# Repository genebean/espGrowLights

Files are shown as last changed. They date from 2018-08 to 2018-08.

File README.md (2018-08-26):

# espGrowLights

espGrowLights is an Arduino sketch for setting up a NodeMCU 1.0 (ESP-12E) to
control the grow lights for our house plants.

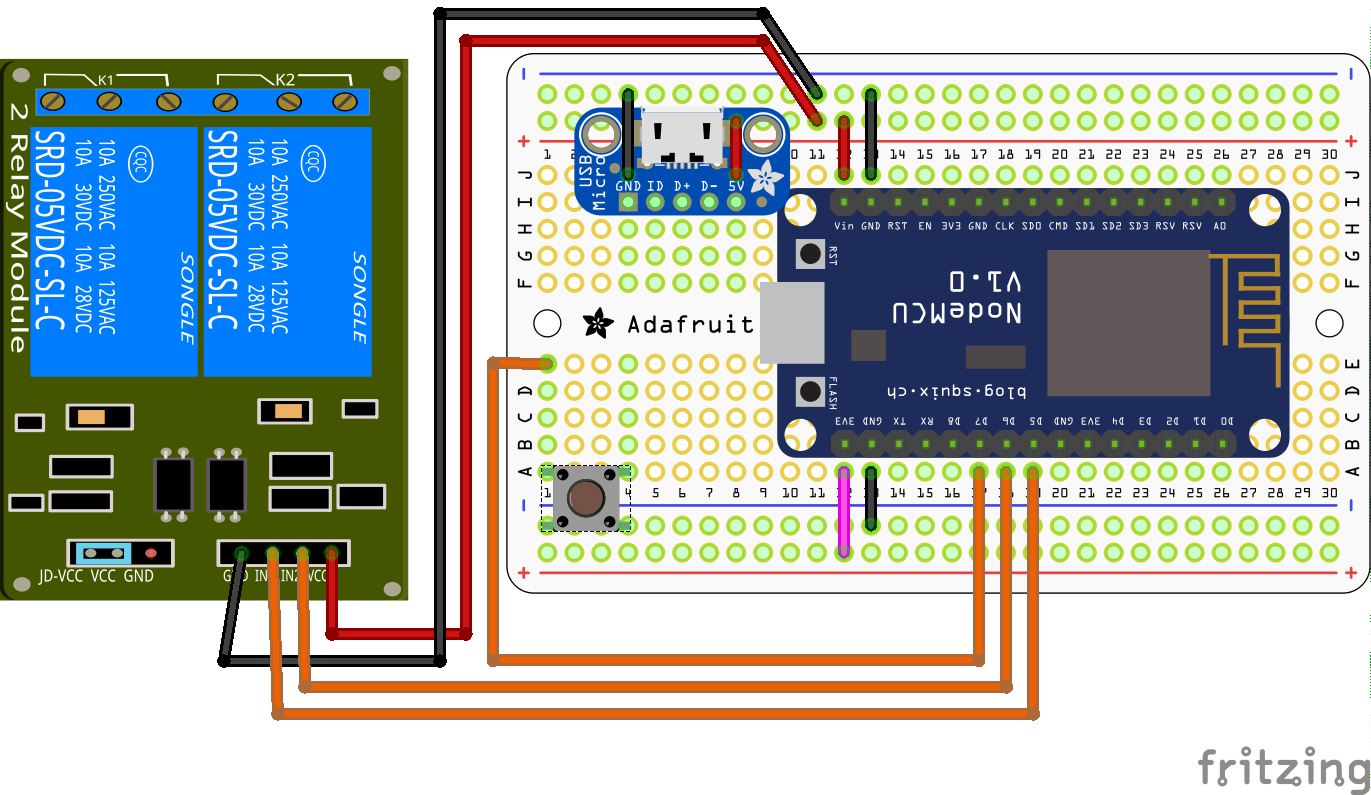
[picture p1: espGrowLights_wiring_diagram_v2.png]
Fritzing wiring diagram v1


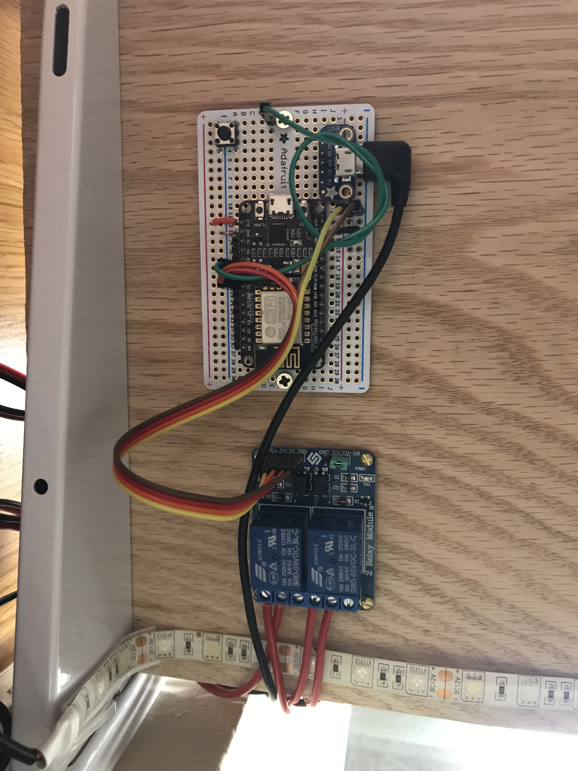
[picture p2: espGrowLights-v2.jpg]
Photo of espGrowLight-v2


To use this sketch you will need to copy `config.sample.h` to
`config.h` and edit it for your wifi (these modules only support 2.4GHz).
You may also want to change the device names in `config.sample.h`.

## Usage

espGrowLights emulates two Belkin Wemo smart plugs that can be
discovered by an Echo so long as they are on the same network. The first device
is the builtin LED. The second controls both relays.

### Alexa

To turn on the grow lights simply say "Alexa, turn on the disco lights."
To trun on the on board led you can say "Alexa, turn on the esp led."

_You may have noticed that I call the grow lights disco lights... thats because
Alexa kept thinking I was saying "garage lights" when I actually said
"grow lights." The lights have a bit of a disco feel and that is not similar to
other words so it should keep her from getting cofused._

### Button

There is also a momentary push button on the edge of the board that can be used
to toggle the grow lights on or off. The code for this button includes logic to
make it only respond about every 3 seconds after its first pressed. This is so
that you don't end up rappidly turning the lights on and off multiple times. If
you want to toggle the lights more than once you can either wait a moment or
just hold the button down.

### Auto on/off schedule

A schedule has also been incorporated into this so that our lights turn
themselves on every morning and off every evening. The on and off hours are also
in `config.sample.h`. Note that the off hour uses the 24-hour format. Lastly,
note also that there are also settings for your timezone. I have included sample
entries for UTC and US Eastern (with and without daylight savings).

## Updates and troubleshooting

I've added mDNS so that you can verify the device is up by browsing to
http://espGrowLights.local or pinging `espGrowLights.local`. That name
corresponds to the `HOST_NAME` entry in `config.sample.h`. This page also acts
as a sudo console that displays log messages. This allows for basic debugging
withoug connecting to the serial port.

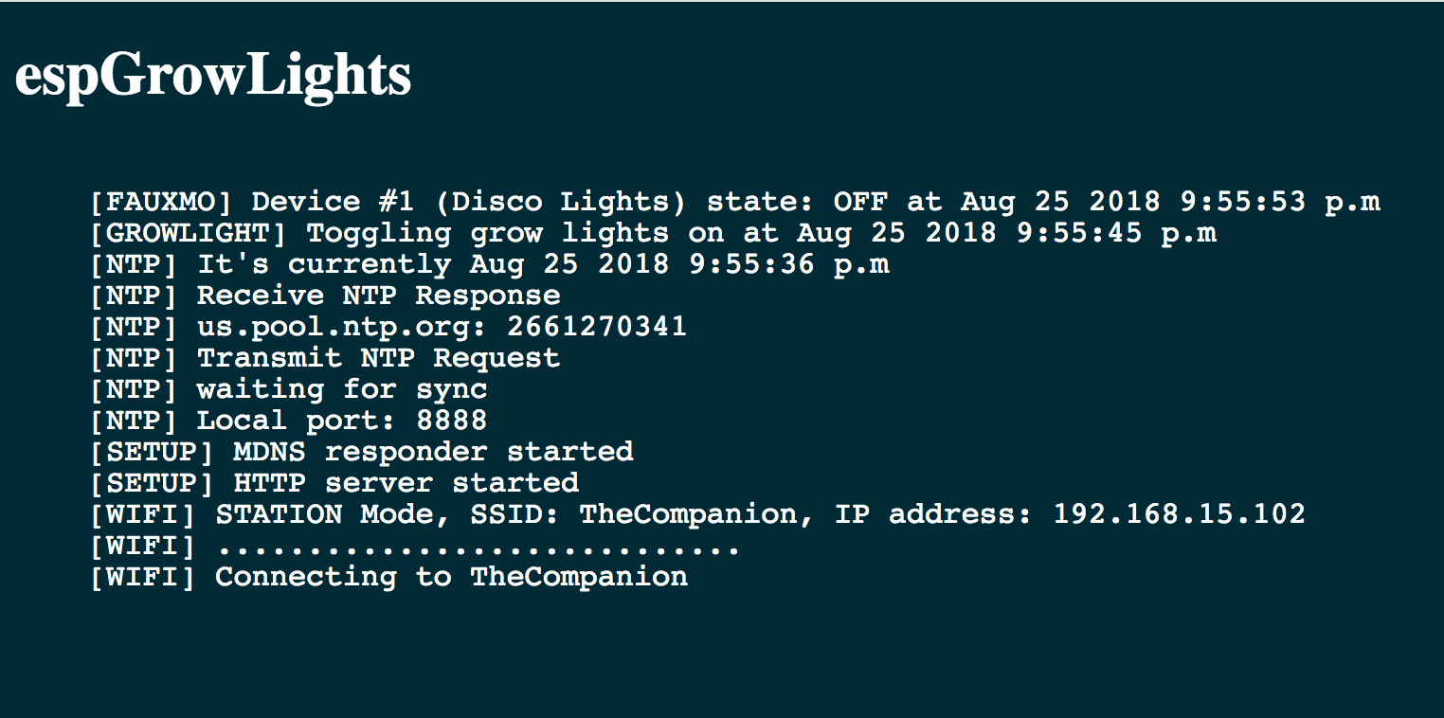
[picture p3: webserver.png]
webserver screenshot


_Note: the page automatically refreshes every 30 seconds._

Once the initial setup is done you can push updates OTA directly from the
Arduino IDE without having to connect to it physically so long as you are on the
same network.

## Parts used

- [Ledy Led Grow Light With DC 12V 2A Adaptor](http://a.co/d/iLA3llI)
- [HiLetgo ESP8266 NodeMCU](http://a.co/hMjdhsX)
- [SunFounder 2 Channel DC 5V Relay Module](http://a.co/5G3O3XI)
- [Tactile Button switch (6mm)](https://www.adafruit.com/product/367)
- [2.1mm x 5.5 mm DC Power Pigtail Cables](http://a.co/dTNQlda)
- [Adafruit USB Micro-B Breakout Board](https://www.adafruit.com/product/1833)
- [Adafruit Perma-Proto Half-sized Breadboard PCB](https://www.adafruit.com/product/1609)
- [Spare Apple 5W USB Power Adapter](https://www.apple.com/shop/product/MD810LL/A/apple-5w-usb-power-adapter)
- [StarTech.com 3' USB Cable - A to Right Angle Micro B (UUSBHAUB3RA)](http://a.co/d/ecVLrZ4)
- [#2 x 3/8 in. Round Head Phillips Brass Wood Screw (6-Piece/Bag)](https://www.homedepot.com/p/Everbilt-2-x-3-8-in-Round-Head-Phillips-Brass-Wood-Screw-6-Piece-Bag-809901/204587524)
- [2mm Pitch 40-Pin Break-apart Male Headers](https://www.adafruit.com/product/2671)
- [Red Solid-Core Wire](https://www.adafruit.com/product/288)
- [Black Solid-Core Wire](https://www.adafruit.com/product/290)
- [Female/Female Jumper Wires](https://www.adafruit.com/product/266)

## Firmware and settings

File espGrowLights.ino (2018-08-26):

#include <Arduino.h>
#include <ArduinoOTA.h>
#include <CircularBuffer.h>
#include <ESP8266WiFi.h>
#include <ESP8266mDNS.h>
#include <ESP8266WebServer.h>
#include <fauxmoESP.h>
#include <TimeLib.h>
#include <WiFiUdp.h>
#include "config.h"

fauxmoESP fauxmo;
ESP8266WebServer server(80);

time_t lastButtonToggle = 0;

// Buffer to hold log entires for web page
CircularBuffer<String, 50> buffer;

// -----------------------------------------------------------------------------
// NTP
// -----------------------------------------------------------------------------
unsigned int localPort = 8888;      // local port to listen for UDP packets
const int NTP_PACKET_SIZE = 48;     // NTP time is in the first 48 bytes of message
byte packetBuffer[NTP_PACKET_SIZE]; //buffer to hold incoming & outgoing packets
WiFiUDP Udp;
time_t prevDisplay = 0;             // when the digital clock was displayed

// -----------------------------------------------------------------------------
// Setup
// -----------------------------------------------------------------------------
void setup() {
  // LED
  pinMode(LED, OUTPUT);
  digitalWrite(LED, HIGH);

  // Grow lights
  pinMode(TOP_GROWLIGHT, OUTPUT);
  digitalWrite(TOP_GROWLIGHT, HIGH);
  pinMode(BOTTOM_GROWLIGHT, OUTPUT);
  digitalWrite(BOTTOM_GROWLIGHT, HIGH);

  // Button
  pinMode(BUTTON, INPUT_PULLUP);

  setupSerial();
  setupWifi();
  setupOTA();
  setupFauxmo();
  setupWebserver();
  setupNTP();
}

// -----------------------------------------------------------------------------
// Loop
// -----------------------------------------------------------------------------
void loop() {
  ArduinoOTA.handle();
  fauxmo.handle();

  static unsigned long last = millis();
  if (millis() - last > 5000) {
    last = millis();
    // Serial.printf("[MAIN] Free heap: %d bytes\n", ESP.getFreeHeap());
  }

  if (timeStatus() != timeNotSet) {
    if (now() != prevDisplay) { //update the display only if time has changed
      prevDisplay = now();
//      Serial.println(timeString());
    }
  }

  handleButtonPush();
  growLightAutoOnOff();
  server.handleClient();
}
// -----------------------------------------------------------------------------
// espGrowLights functions
// -----------------------------------------------------------------------------
void setGrowLightState(bool state) {
  //    Serial.printf("[GROWLIGHT] Setting state to : %s\n", state ? "ON" : "OFF");
  digitalWrite(TOP_GROWLIGHT, !state);
  digitalWrite(BOTTOM_GROWLIGHT, !state);
}

bool getGrowLightState() {
  bool top_growlight_state = !digitalRead(TOP_GROWLIGHT);
  bool bottom_growlight_state = !digitalRead(BOTTOM_GROWLIGHT);
  bool state;
  if (top_growlight_state && bottom_growlight_state) {
    state = true;
  } else {
    state = false;
  }
  //    Serial.printf("[GROWLIGHT] Both grow lights are %s\n", state ? "on" : "off");
  return state;
}

void growLightAutoOnOff() {
  // Turn the grow lights on and off at specified times
  if (hour() == lightOnHour && minute() == lightOnMin && second() == 0 && !getGrowLightState()) {
    logger("[GROWLIGHT] It's " + timeString() + " turning on the grow lights.");
    setGrowLightState(true);
  } else if (hour() == lightOffHour && minute() == lightOffMin && second() == 0 && getGrowLightState()) {
    logger("[GROWLIGHT] It's " + timeString() + " turning off the grow lights.");
    setGrowLightState(false);
  }
}

void handleButtonPush() {
  int buttonState = digitalRead(BUTTON);

  // check if the pushbutton is pressed. If it is, the buttonState is LOW.
  // toggle ligths if time has changed since last press
  if (buttonState == LOW) {
    if (now() != lastButtonToggle && (now()-1) != lastButtonToggle && (now()-2) != lastButtonToggle) {
      lastButtonToggle = now();
      bool currentState = getGrowLightState();
      setGrowLightState(!currentState);
      String onOff = !currentState ? "on" : "off";
      logger("[GROWLIGHT] Toggling grow lights " + onOff + " at " + timeString());
    }
  }
}

void logger(String msg) {
  unsigned int msgLength = msg.length() + 1;
  char msgChars[msgLength];
  msg.toCharArray(msgChars, msgLength);
  Serial.println(msgChars);
  buffer.unshift(msg);
}

// -----------------------------------------------------------------------------
// Setup functions called in setup()
// -----------------------------------------------------------------------------
void setupFauxmo() {
  // Disabling fauxmo will prevent the devices from being discovered and switched
  fauxmo.enable(true);

  // Virtual Wemo devices
  fauxmo.addDevice(LED_DEVICE_NAME);
  fauxmo.addDevice(DEVICE_NAME);

  fauxmo.onSetState([](unsigned char device_id, const char * device_name, bool state) {
    String onOff = state ? "ON" : "OFF";
    logger("[FAUXMO] Device #" + String(device_id) + " (" + device_name + ") state: "+ onOff + String(" at ") + timeString());
    switch (device_id) {
      case 0:
        digitalWrite(LED, !state);
        break;
      case 1:
        setGrowLightState(state);
        break;
      default:
        logger("[FAUXMO] Device #" + String(device_id) + " (" + device_name + ") not found in switch case statement");
        break;
    }
  });

  // Callback to retrieve current state (for GetBinaryState queries)
  fauxmo.onGetState([](unsigned char device_id, const char * device_name) {
    switch (device_id) {
      case 0:
        return !digitalRead(LED);
        break;
      case 1:
        return getGrowLightState();
        break;
      default:
        logger("[FAUXMO] Device #" + String(device_id) + " (" + device_name + ") not found in switch case statement");
        break;
    }
  });
}

void setupNTP() {
  Udp.begin(localPort);
  logger("[NTP] Local port: " + String(Udp.localPort()));
  logger("[NTP] waiting for sync");
  setSyncProvider(getNtpTime);
  setSyncInterval(300);
  logger("[NTP] It's currently " + timeString());
}

void setupOTA() {
  // Port defaults to 8266
  // ArduinoOTA.setPort(8266);

  // Hostname defaults to esp8266-[ChipID]
  ArduinoOTA.setHostname(HOST_NAME);

  // No authentication by default
  // ArduinoOTA.setPassword((const char *)"123");

  ArduinoOTA.onStart([]() {
    Serial.println("[OTA] Start");
  });
  ArduinoOTA.onEnd([]() {
    Serial.println("\n[OTA] End");
  });
  ArduinoOTA.onProgress([](unsigned int progress, unsigned int total) {
    Serial.printf("[OTA] Progress: %u%%\r", (progress / (total / 100)));
  });
  ArduinoOTA.onError([](ota_error_t error) {
    Serial.printf("[OTA] Error[%u]: ", error);
    if (error == OTA_AUTH_ERROR) Serial.println("[OTA] Auth Failed");
    else if (error == OTA_BEGIN_ERROR) Serial.println("[OTA] Begin Failed");
    else if (error == OTA_CONNECT_ERROR) Serial.println("[OTA] Connect Failed");
    else if (error == OTA_RECEIVE_ERROR) Serial.println("[OTA] Receive Failed");
    else if (error == OTA_END_ERROR) Serial.println("[OTA] End Failed");
    ESP.restart();
  });
  ArduinoOTA.begin();
}

void setupSerial() {
  // Init serial port and clean garbage
  Serial.begin(SERIAL_BAUDRATE);
  Serial.println();
}

void setupWebserver() {
  server.on("/", handleRoot);
  server.onNotFound(handleNotFound);

  server.begin();
  logger("[SETUP] HTTP server started");

  if (MDNS.begin(HOST_NAME)) {
    logger("[SETUP] MDNS responder started");
  }
}

void setupWifi() {

  // Set WIFI module to STA mode
  WiFi.mode(WIFI_STA);

  // Connect
  logger("[WIFI] Connecting to " + String(WIFI_SSID));
  WiFi.begin(WIFI_SSID, WIFI_PASS);

  // Wait
  String dots = "[WIFI] ";
  Serial.print("[WIFI] ");
  while (WiFi.status() != WL_CONNECTED) {
    Serial.print(".");
    dots += ".";
    delay(100);
  }
  Serial.println();
  buffer.unshift(dots);

  // Connected!
  logger("[WIFI] STATION Mode, SSID: " + WiFi.SSID() + ", IP address: " + WiFi.localIP().toString().c_str());
}

// -----------------------------------------------------------------------------
// Webserver functions
// -----------------------------------------------------------------------------
void handleRoot() {
  String html = "<!DOCTYPE html>";
  html += "<html>";
  html += "<meta http-equiv='refresh' content='30'/>";
  html += "<title>" + String(HOST_NAME) + "</title>";
  html += "<style>";
  html += "  body {";
  html += "    background-color: #002b36;";
  html += "    color: white;";
  html += "  }";
  html += "  pre {";
  html += "    font-size: large;";
  html += "    width: 100%;";
  html += "    display: inline-block;";
  html += "  }";
  html += "</style>";
  html += "<body>";
  html += "  <h1>" + String(HOST_NAME) + "</h1>";
  html += "  <pre>";
  for (unsigned int i = 0; i < buffer.size(); i++) {
    html += "    " + buffer[i] + "<br />";
  }
  html += "  </pre>";
  html += "</body>";
  html += "</html>";
  server.send(200, "text/html", html);
}

void handleNotFound() {
  String message = "404... couldn't find\n\n";
  message += "URI: ";
  message += server.uri();
  message += "\nMethod: ";
  message += (server.method() == HTTP_GET) ? "GET" : "POST";
  message += "\nArguments: ";
  message += server.args();
  message += "\n";
  for (uint8_t i = 0; i < server.args(); i++) {
    message += " " + server.argName(i) + ": " + server.arg(i) + "\n";
  }
  server.send(404, "text/plain", message);
}

// -----------------------------------------------------------------------------
// NTP functions
// -----------------------------------------------------------------------------
String timeString() {
  const String timeSep = ":";
  const String space = " ";
  String theTime = monthShortStr(month()) + space + day() + space + year() + space + hourFormat12() + timeSep;
  if (minute() < 10) {
    theTime += "0";
  }
  theTime += minute() + timeSep;
  if (second() < 10) {
  theTime += "0";
  }
  theTime += second();
  if (isAM()) {
    theTime += " a.m.";
  } else {
    theTime += " p.m.";
  }
  return theTime;
}

time_t getNtpTime() {
  IPAddress ntpServerIP; // NTP server's ip address

  while (Udp.parsePacket() > 0) ; // discard any previously received packets
  Serial.println("[NTP] Transmit NTP Request");
  // get a random server from the pool
  WiFi.hostByName(ntpServerName, ntpServerIP);
  Serial.print("[NTP] ");
  Serial.print(ntpServerName);
  Serial.print(": ");
  Serial.println(ntpServerIP);
  sendNTPpacket(ntpServerIP);
  uint32_t beginWait = millis();
  while (millis() - beginWait < 1500) {
    int size = Udp.parsePacket();
    if (size >= NTP_PACKET_SIZE) {
      Serial.println("[NTP] Receive NTP Response");
      Udp.read(packetBuffer, NTP_PACKET_SIZE);  // read packet into the buffer
      unsigned long secsSince1900;
      // convert four bytes starting at location 40 to a long integer
      secsSince1900 =  (unsigned long)packetBuffer[40] << 24;
      secsSince1900 |= (unsigned long)packetBuffer[41] << 16;
      secsSince1900 |= (unsigned long)packetBuffer[42] << 8;
      secsSince1900 |= (unsigned long)packetBuffer[43];
      return secsSince1900 - 2208988800UL + timeZone * SECS_PER_HOUR;
    }
  }
  Serial.println("[NTP] No NTP Response :-(");
  return 0; // return 0 if unable to get the time
}

// send an NTP request to the time server at the given address
void sendNTPpacket(IPAddress &address) {
  // set all bytes in the buffer to 0
  memset(packetBuffer, 0, NTP_PACKET_SIZE);
  // Initialize values needed to form NTP request
  // (see URL above for details on the packets)
  packetBuffer[0] = 0b11100011;   // LI, Version, Mode
  packetBuffer[1] = 0;            // Stratum, or type of clock
  packetBuffer[2] = 6;            // Polling Interval
  packetBuffer[3] = 0xEC;         // Peer Clock Precision
  // 8 bytes of zero for Root Delay & Root Dispersion
  packetBuffer[12] = 49;
  packetBuffer[13] = 0x4E;
  packetBuffer[14] = 49;
  packetBuffer[15] = 52;
  // all NTP fields have been given values, now
  // you can send a packet requesting a timestamp:
  Udp.beginPacket(address, 123); //NTP requests are to port 123
  Udp.write(packetBuffer, NTP_PACKET_SIZE);
  Udp.endPacket();
}

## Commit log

2018-08-21 Added Fritzing diagram
    [espGrowLights.fzz]
2018-08-23 Added toggle via momentary button
    [espGrowLights.fzz]
2018-08-23 Updated docs, moved all user variables to config.h
    [espGrowLights.fzz]
2018-08-26 Check state before automatic on/off
    The state check fixes an issue where the log was being spam during each
    cycle during a 1 second period because the auto on/of function was
    repeatedly trying to set the lights' state.
    Also added the ability to configure the minute at which the lights turn
    on or off to the config file.
    [espGrowLights.ino]
